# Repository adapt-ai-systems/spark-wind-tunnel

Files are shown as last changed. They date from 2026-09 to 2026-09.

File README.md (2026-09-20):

# spark-tunnel-share — a 3D-printed wind tunnel for two NVIDIA DGX Sparks

A printed ducted box that force-cools **two DGX Spark mini computers
stacked flat**, one above the other, with a single 140 mm fan at the front
and an open rear. Three of these cases were built and put into daily
service; this repo is the version-four design exactly as built — the CAD,
the printable STLs, the settings that worked, and the ones that didn't.

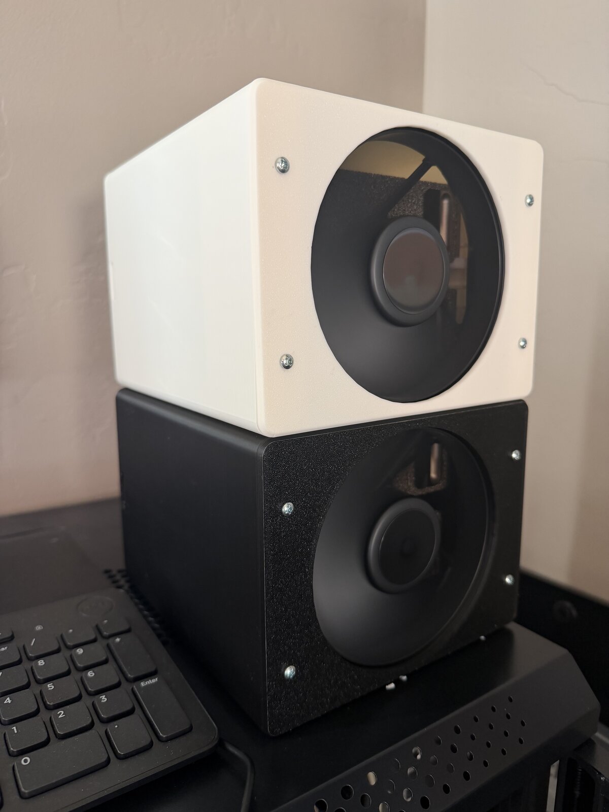
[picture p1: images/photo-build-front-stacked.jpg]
Assembled cases


## What v4 is

Two Sparks lie flat, one above the other, behind a screwed-on fan bezel,
with the rear open. Versus the earlier versions (see
[docs/DESIGN-HISTORY.md](docs/DESIGN-HISTORY.md)):

- **No center tray.** An earlier design supported the upper machine on a
  middle plate; it was 2–3 mm too tight and printed badly. The upper Spark
  now rides on **C-channel side supports** molded into the side walls: a
  reinforced bottom ledge, a top ledge, and flow-parallel ribs between.
- **Positive retention.** The fan bezel is **screwed** on with four #6-32
  screws and the rear locking bar is screwed down with one more — no
  friction fits or snap hooks holding the computers in.
- **Vented rear bar (rev 8).** The solid rear bar blocked the rear exit of
  the 17 mm air gap between the Sparks; it now has seven 20 x 15 mm windows
  while the 3 mm retaining lips stay solid.

Air path: fan → plenum → through both Sparks and around them through an
equal 17 mm gap on every side → open rear. The equal-gap layout and the
opening-area reasoning are in [docs/SPEC.md](docs/SPEC.md); measured cooling
numbers (and their honest limits) are in [docs/THERMAL.md](docs/THERMAL.md).

## Printed parts

| Part | STL | Print time | Material | Notes |
|---|---|---|---|---|
| Body | [stl/body.stl](stl/body.stl) | ~12 h | ~720 g PLA | prints rear face down, warp recipe (see below) |
| Bezel | [stl/bezel.stl](stl/bezel.stl) | 58–69 min | ~50 g PLA | front face down |
| Lock bar | [stl/lockbar.stl](stl/lockbar.stl) | ~30 min | ~20 g PLA | vented rev 8, rear face down |

Print settings and the failure log that produced them — corner warping, the
brim widths that fixed it, bed temperature, and a nozzle-blob/first-layer
story — are in [docs/PRINT-NOTES.md](docs/PRINT-NOTES.md). The short
version: PLA, bed 65 °C, 15 mm inner+outer brim on the body, part fan
15–30 % and off for the first five layers, one part per plate.

## Bill of materials

| Item | Qty | Spec |
|---|---|---|
| NVIDIA DGX Spark | 2 | 45 x 150 x 150 mm body (measured) |
| Arctic P14 Pro fan | 1 | 140 x 140 x 27 mm, 4-pin, 400–2500 rpm |
| #6-32 screws | 5 | 4x bezel into the printed fan rails, 1x lock-bar tab into the wall pad |
| PLA filament | ~800 g | per case |
| Printed parts | 3 | above |

The pedestal height and flare dimensions used in the CAD are from the
community design [jvr0x/dgx-spark-rack](https://github.com/jvr0x/dgx-spark-rack)
(measured from a reference STL) — worth verifying against your own machine
with a rule; the box geometry is parametric if you need to adjust.

## Regenerating the STLs from the CAD

The single parametric source is `cad/spark-box-v4.scad` (OpenSCAD). Each
part module also outputs in its print orientation:

```sh
openscad -o stl/body.stl    -D 'part="body"'    cad/spark-box-v4.scad
openscad -o stl/bezel.stl   -D 'part="bezel"'   cad/spark-box-v4.scad
openscad -o stl/lockbar.stl -D 'part="lockbar"' cad/spark-box-v4.scad
```

`part="assembly"` and `part="cutaway"` (the default is assembly) render the
full box; a set of `chk_*` parts support the fit checks. The file also
echoes the front-face vs bypass-gap area ratio on every load.

## Photos

Assembled black and white cases, front and rear:

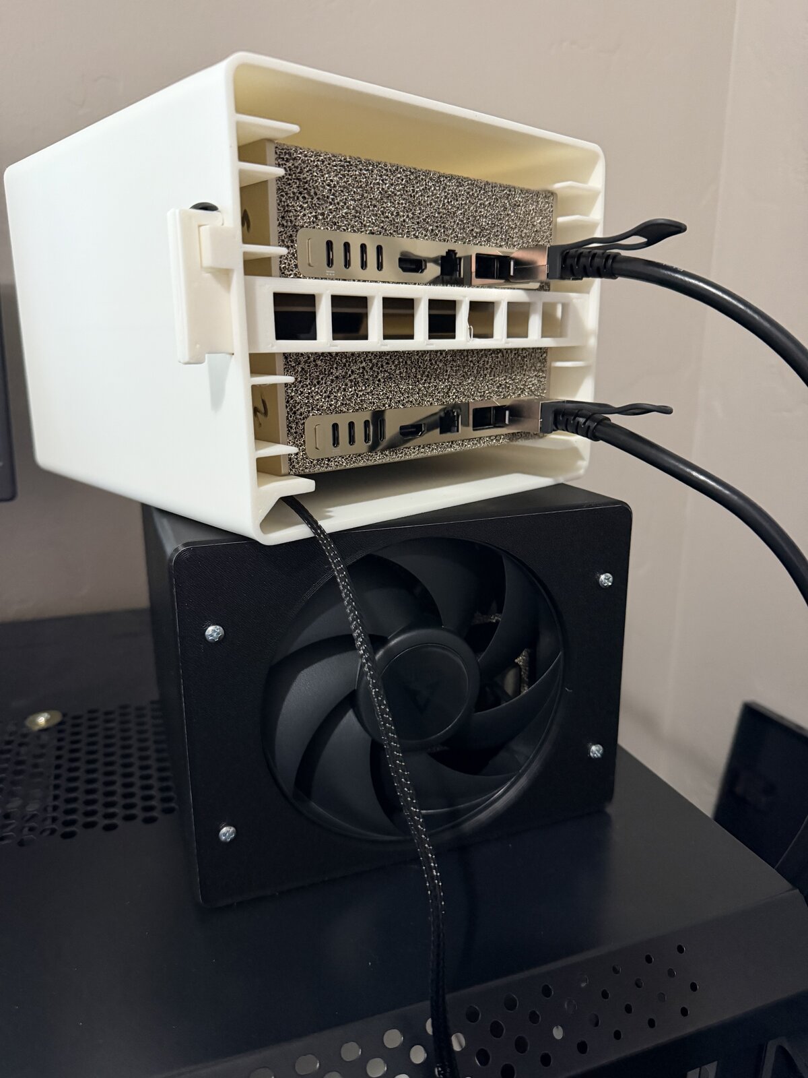
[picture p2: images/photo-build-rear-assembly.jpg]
Rear, white over black

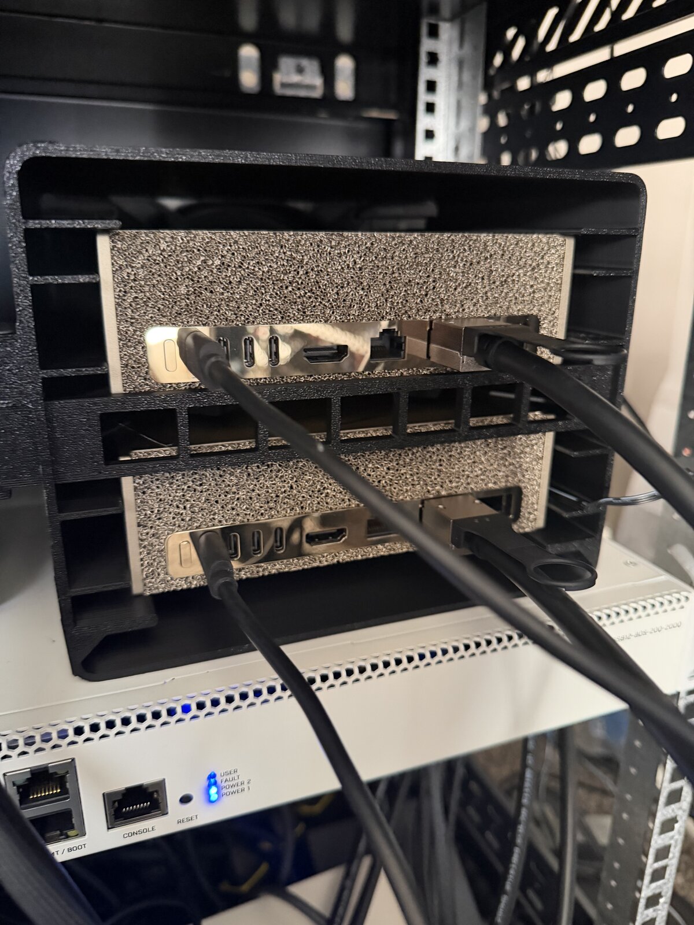
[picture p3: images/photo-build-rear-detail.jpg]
Rear detail, vented lock bar and I/O access


CAD renders (OpenSCAD):

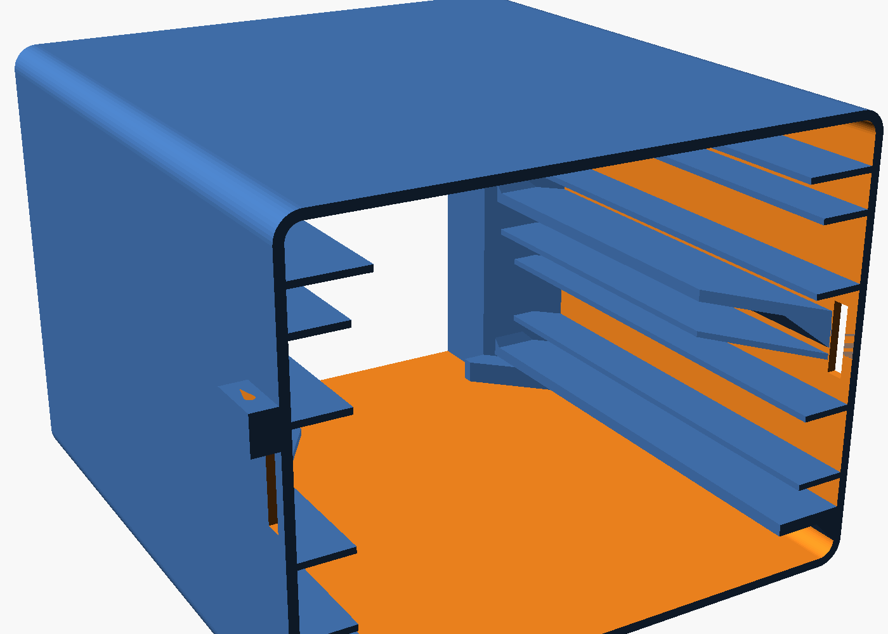
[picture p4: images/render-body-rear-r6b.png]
Body with rear ledges

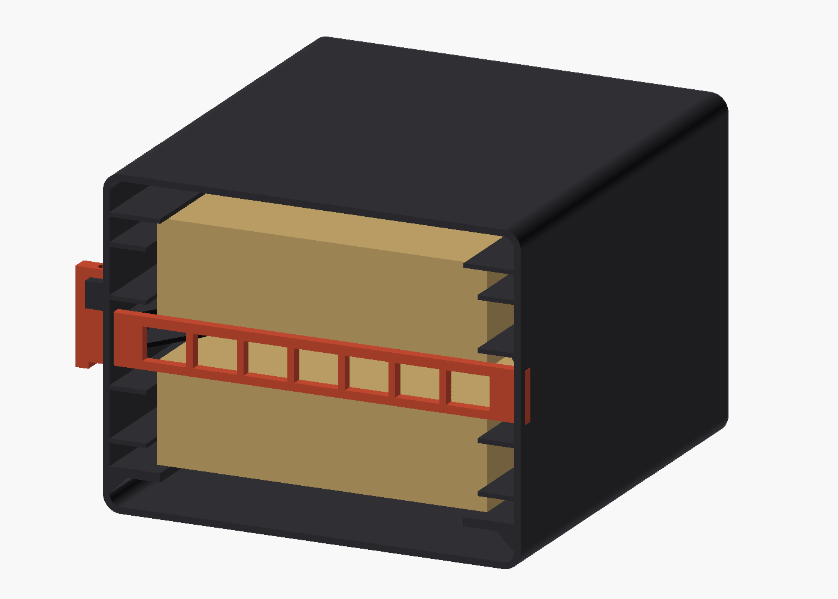
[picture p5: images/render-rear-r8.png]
Rear, rev 8

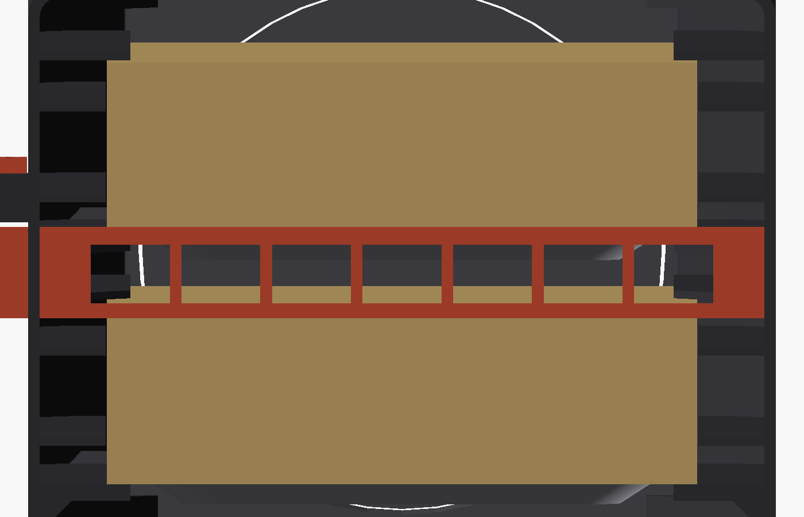
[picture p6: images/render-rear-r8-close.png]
Rear close, rev 8

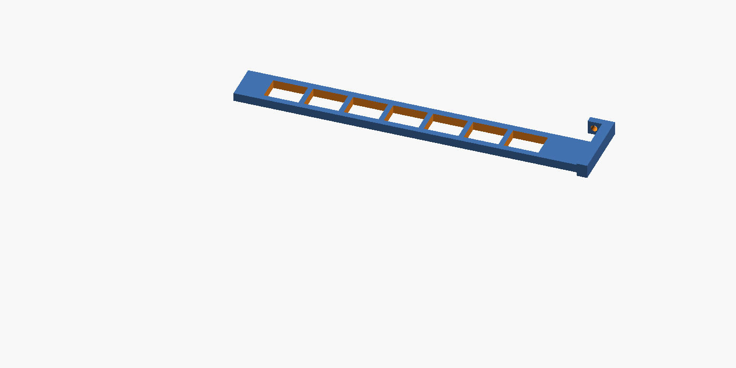
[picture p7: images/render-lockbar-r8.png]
Lock bar rev 8


## Credit

- [jvr0x/dgx-spark-rack](https://github.com/jvr0x/dgx-spark-rack) —
  measured DGX Spark pedestal dimensions used in the CAD.
- The rear locking-bar concept follows the community "whpthomas" rack bar
  idea, adapted to screwed retention and ventilation.

## License

MIT — see [LICENSE](LICENSE). Copyright (c) 2026 spark-tunnel-share
contributors.

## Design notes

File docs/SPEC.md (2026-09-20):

# Original requirements spec (Stage 0)

This is the requirements document written before the first build of this design family; the file it describes became the shipped CAD as `cad/spark-box-v4.scad`.

Owner: the project owner. Lines are the owner's words or numbers unless marked
(design note). "Assumed" means unmeasured and blocks Stage 1.

## Layout (owner, 2026-09-09)

| # | Requirement | Source |
|---|---|---|
| L1 | Two Sparks stacked flat, one above the other | "stacked is fine as long as there is a gap around them" |
| L2 | A gap around the exterior of each Spark; the metal shell dissipates heat and must be cooled | "the exterior of the sparks are metal and are designed to dissipate heat" |
| L3 | Sides solid, no honeycomb | v1 feedback |
| L4 | Front centre strip solid (v1 ribs snapped) | v1 feedback |
| L5 | Sparks held tight, enclosed, not loose | v1 feedback; whpthomas locking bar liked |
| L6 | Power button reachable with the box assembled | v1 feedback; in the stacked layout the rear is open so L6 is met by layout |
| L7 | Fan plug fits its exit; cord exit does not block plugging the Sparks in | v1 feedback |

## Airflow (owner, 2026-09-09)

| # | Requirement | Source |
|---|---|---|
| A1 | Fan: the owner's 140 mm (Arctic P14 Pro) | "the fan is my 140" |
| A2 | Air must exit around the Sparks as well as through them | "We will need air exiting around the sparks" |
| A3 | Opening AREA ratio 70:30, Spark faces to bypass gap (fixed geometry, no shutter) | "Let's just do like 70/30 face to gap ratio" (2026-09-09) |
| A3b | SUPERSEDES A3 (rev 4, later on 2026-09-09): equal gap on every side of the Sparks and between them; with the 141 mm interior that is 17 mm and the area ratio becomes 54:46 | "I want equal space between the sparks as is around them" |
| A4 | The around-path is a thin gap held off the shell by ribs parallel to the airflow | "a thin area around them held out by ribs that are parallel to wind-flow" |
| A5 | Cooling test on v1 decides the bottom-intake positions (v1 plan) | earlier |

## Mating objects

| Object | Dimension | Value | Source | Status |
|---|---|---|---|---|
| Spark | body W x L x H | 45 x 150 x 150 | caliper measurement 2026-09-05 | measured |
| Spark | pedestal height | 6 | jvr0x/dgx-spark-rack README (measured from reference STL; teardowns 51.2 total) | from community STL, verify with a rule |
| Spark | pedestal flare | 111 x 101 at the desk -> 128.6 x 118.6 at the chassis, i.e. ~8.8 mm run per side over the 6 mm height | jvr0x README | from community STL, verify |
| Spark | overall height incl. pedestal | 51.5 | jvr0x README / NVIDIA 50.5 | published |
| Spark | power button | on the BACK, above the USB-C power port | owner, 2026-09-09 | stated |
| Fan plug | standard 4-pin fan plug ("square 4pin"): 2.54 pitch housing ~10.7 x 6.6 mm, ~8 mm tall; cable 400 mm | operator + Arctic spec sheet + Molex KK254 housing dims | housing size from catalog, verify in hand |
| P14 Pro | 140 x 140 x 27 mm, 240 g, 400-2500 rpm, 110 cfm, 5.2 mmH2O, 12 V 0.35 A, cable 400 mm, 4-pin fan plug | Arctic spec sheet PDF | catalog; hole spacing 124.5 assumed (standard 140), verify |

## Open (design note)

- A3 is an AREA ratio by the owner's decision; the resulting flow split is
  unknown until the cooling test (A5). It was flagged that the gap will carry
  more than 30 % of the flow because it has less resistance than the Spark;
  the owner chose the fixed ratio anyway.

## Rev 5 (2026-09-10, owner, after the first full print)

| # | Requirement | Source |
|---|---|---|
| R1 | Screws hold the fan shroud (bezel), not hooks | "screws to hold the fan shroud, not hooks" |
| R2 | The tray (middle layer) must print cleanly, no fused support | "the middle layer print was messed up so we need to do that better next time" |
| R3 | No friction retention; assembled box is one secure unit | "I don't like friction holding something... This needs to act as one secure unit" |
| R4 | Screws: #6-32 (owner wrote "6-29", read as 6-32) | chat |

## Rev 6 (2026-09-10, owner): no tray

| # | Requirement | Source |
|---|---|---|
| R5 | The Sparks are locked in by the ribs on the sides and do not require a support in between them | "the sparks should be locked in by the ribs on the sides and should not require a support in between them" |

## Rev 6b (2026-09-11, owner): reinforce the load-bearing ledge

| # | Requirement | Source |
|---|---|---|
| R6 | Bottom ledges 4 mm thick with an 8 mm 45-degree gusset to the wall | fit feedback on the weight-bearing ledges |

## Rev 8 (2026-09-13): vented lock bar

The solid rear bar blocked the rear exit of the 17 mm gap between the Sparks.
Rev 8 adds a row of seven 20 x 15 mm windows across that band; the 3 mm lips
that retain the Sparks stay solid.

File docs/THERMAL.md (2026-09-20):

# Cooling evidence — one short load test, honestly bounded

## Finding

A September 9 sample run shows a **10.2 °C sample-average GPU-temperature
difference** between the two machine pairs: the pair installed in an
enclosure ran cooler than the pair outside one. This is consistent with the
owner's recollection of roughly 10–15 ° cooler operation.

**Caveat up front:** the test predates the version-four case in this repo,
and the tested case revision is not recorded. Treat this as evidence for the
wind-tunnel project overall, not a validation of the exact design here.

## Method as recorded

- Date: September 9, 15:32 UTC. Four NVIDIA DGX Spark machines had their
  1989 MHz clock lock removed for the test and restored afterwards.
- Load: five minutes of parallel inference requests against one shared
  model endpoint served by the four machines as a tensor-parallel ring —
  not four independent workloads.
- Sampling: the four machines were queried sequentially with
  `nvidia-smi` (GPU temperature, graphics clock, reported GPU power,
  utilization) with a 15 s sleep between rounds; 21 rounds, 84
  observations. The labels 0s–300s are nominal: query overhead adds time,
  readings are not simultaneous. This is an *intended five-minute load
  test*, not a timed steady-state experiment.

## Results

Machines relabeled; the original pairing is preserved.

| Unit | Group | First recorded °C | Last recorded °C | Peak recorded °C | Mean of 21 samples °C |
|---|---|---:|---:|---:|---:|
| Tunnel A | Enclosed | 36 | 53 | 53 | 50.38 |
| Tunnel B | Enclosed | 35 | 51 | 54 | 47.95 |
| Compare A | Open | 43 | 63 | 66 | 57.95 |
| Compare B | Open | 45 | 65 | 69 | 60.86 |

| Statistic | Value | Note |
|---|---:|---|
| Pair means, all 21 rounds | 49.17 °C vs 59.40 °C | difference **10.24 °C**; unweighted sample average, includes warm-up |
| Final five rounds (nominal 240–300 s) | difference **12.80 °C** | descriptive late-window subset, not an independently defined steady state |
| Final recorded round | 53/51 °C vs 63/65 °C | difference **12.0 °C** |
| Per-machine peaks | 53/54 °C vs 66/69 °C | difference of peak means **14.0 °C**; peaks are a different statistic, do not substitute for the average |

## What the raw record does **not** support

- **Not identical operating points.** Across the record, graphics clocks
  span 2405–2528 MHz and reported GPU power spans 12.08–40.72 W; the warmer
  pair generally drew more reported power.
- **No demonstrated steady state** for every machine; one unit was still
  climbing at the end.
- **No throttle-reason data** in the samples — absence of recorded
  throttling was not verifiable per machine throughout.
- **Throughput figures** quoted in a contemporary chat summary were derived
  by dividing generated output by a hard-coded 300 s window; no
  case-on/case-off speed experiment was performed. Do not use them as
  cooling evidence.

## Limits on causal claims

- This is a **cross-machine comparison, not a controlled before/after
  crossover**. The first recorded pair-mean gap is already 8.5 °C; the first
  sample is not a documented equivalent bare-machine baseline, and the
  enclosed pair may already have benefited from the case at sample one.
- Room temperature, intake-air temperature, placement, fan RPM/duty, exact
  fan model in the tested case, enclosure revision, and repeat trials are
  not documented. Power readings are GPU telemetry, not wall power. One
  short run gives no error bars and no statistical significance.
- The current design's rear ventilation and retention changes happened
  after this test.

## Qualitative update (September 17)

The owner reports the version-four cases run the Sparks at full load without
underclocking, after choosing a higher-speed fan running at roughly half
throttle from two options; noise and airflow comparisons were qualitative.
Reported throughput is unchanged with lower temperatures near 1900 MHz,
without matching clock/workload records. These are user observations, not
measurements included here.

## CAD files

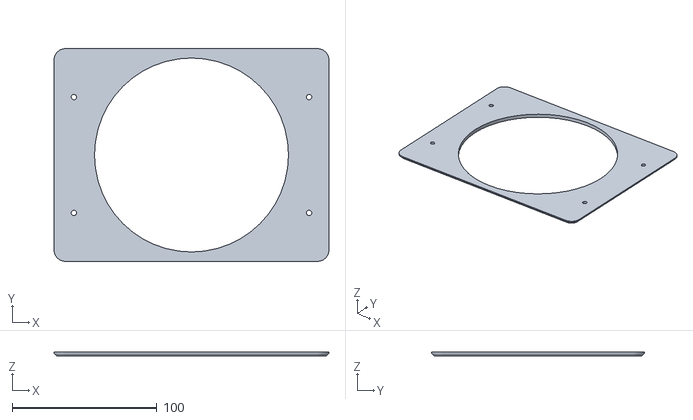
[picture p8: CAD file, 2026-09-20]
stl/bezel.stl
190.0 x 147.0 x 3.00

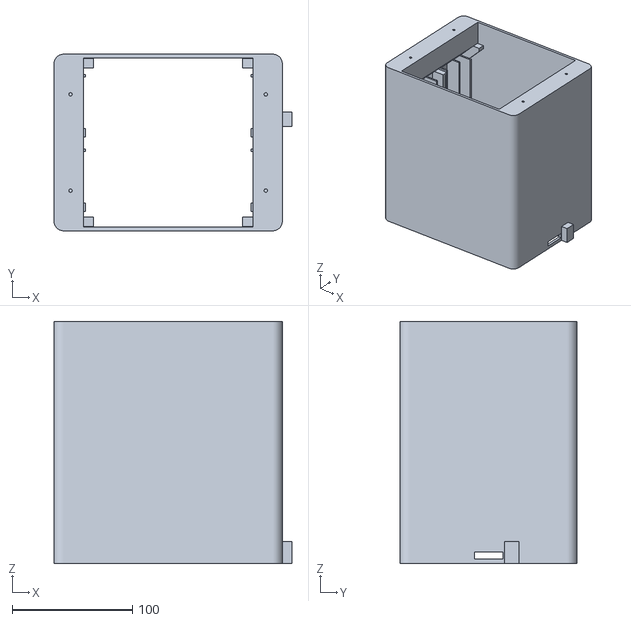
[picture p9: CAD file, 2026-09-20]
stl/body.stl
198.0 x 147.0 x 201.5

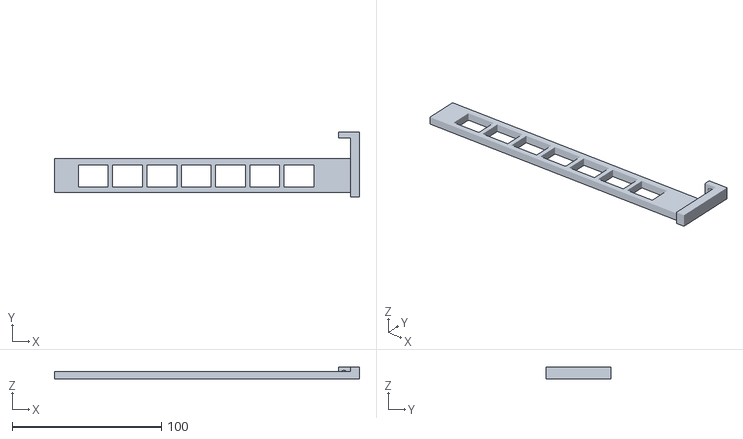
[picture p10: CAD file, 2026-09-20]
stl/lockbar.stl
204.5 x 43.8 x 8.00

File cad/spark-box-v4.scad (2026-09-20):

// Spark box v2 — two DGX Sparks stacked flat inside a ducted box, 140 mm fan at the front, open rear.
// rev 8 (2026-09-13): lock bar vented. The solid bar blocked the rear exit of the 17 mm gap between the Sparks; it now has a row of windows across that band, the 3 mm lips that retain the Sparks stay solid.
// rev 6 (2026-09-10): NO tray. Each Spark is locked in by C-channel ribs on the side walls: a bottom ledge it sits on, a top ledge over it, the lateral side ribs between. Nothing between the Sparks but air.
// rev 5 (2026-09-10, after the first full print): bezel screwed on (4 x #6-32 into the fan rails, hooks gone); lock bar screwed down (#6-32 through a handle tab into a pad on the right wall); tray underside is a flat slab (no support).
// Spec: ../docs/SPEC.md (2026-09-09). Parts: body, bezel, lockbar (rev 6: no tray). Render views at the bottom.
// Every number here is either from SPEC.md or a design choice marked (design note).
$fn = 48; eps = 0.01;

// ---- mating objects (SPEC "Mating objects") ----
sw = 150;  sl = 150;  st = 45;          // Spark body: width, depth (face->rear), thickness (measured 2026-09-05)
ped_h = 6;                              // pedestal height (jvr0x, verify)
ped_top = [128.6, 118.6];  ped_bot = [111, 101];   // pedestal flare, chassis -> desk (jvr0x, verify)
fan = 140; fan_t = 27; fan_hole = 124.5; fan_bore = 134; fan_screw = 5.2;   // P14 Pro spec sheet; hole spacing = standard 140 (verify)

// ---- design choices (design note) ----
wall  = 3;      // all walls
plen_ih = fan + 1;   // interior height 141: fan pocket + clearance (rev 4: one height end to end - simple and smooth)
IH = plen_ih;
g     = (IH - 2*st)/3;   // 17: EQUAL gap everywhere — floor, between the Sparks, ceiling, and both sides (rev 4)
rib_w = 2;      // flow-parallel ribs holding each Spark off the walls (ledge and side rib thickness)
ledge_reach = g + 6;   // (rev 6) 23: side ledges run from the wall to 6 mm under each Spark edge, 4.7 mm outside the 128.6 pedestal flare (same reach as the old rib_x)
ch_cl = 1.0;    // (rev 6) channel height = st + ch_cl: top ledge sits 1.0 above the Spark (printed rib heights stack up)
seat_t = 4;     // (rev 6b: reinforce the ledge carrying the weight) bottom ledge thickness
gus = 8;        // (rev 6b) 45 deg gusset under each bottom ledge: gus down the wall, gus out along the ledge
bezel_t = 3;    // front bezel plate
fan_cl = 0.5;   // fan pocket clearance
stop_d = 4;     // fan rear stop blocks
mix_d = 10;     // fan exhaust -> chamfer start
plen_d = bezel_t + fan_t + fan_cl + stop_d + mix_d;   // plenum depth (44.5)
r_out = 8; r_in = 5;   // outer / inner corner radii (smooth exterior)
hook_w = 10; hook_t = 1.5; hook_l = 9; barb = 1.0;   // bezel snap hooks (4)
rear_d = 10;    // room behind the Sparks for the lock bar and cables
scr_pilot = 2.9; scr_clr = 3.7; scr_x = 13.75;   // (rev 5) #6-32 screws: pilot in plastic, clearance in the part; bezel screws sit in the fan-rail centres x = 13.75 / OW-13.75
bar_t = 5; bar_lip = 3;   // lock bar: thickness, VERTICAL overlap onto each Spark's rear edge (rev 4c: bar_h derived so BOTH Sparks get the full lip; it was 20 = only 0.3 on Spark 2)
vent_w = 20; vent_strut = 3; vent_m = 1.0;   // (rev 8) lock bar vent windows: width, strut between windows, solid margin kept above/below the window inside the inter-Spark gap (windows are vent_h = g - 2*vent_m = 15 tall; lips stay solid)
bar_gap = 0.5;  // slot starts this far behind the Spark rears (bar face 0.8 behind them: fore-aft play, spec L5 "held tight")
stop_h = 3;     // front stop tabs on the rib ends

// ---- derived ----
IW = sw + 2*g;                 // interior width 184
OW = IW + 2*wall;              // 190
OH = IH + 2*wall;              // body outer height 147, front to rear
PH = OH;                       // (plenum outer height = body height)
ch = 0;                        // no chamfer any more
z_floor = wall;
stack_h = st + g + st;   // (rev 6) Spark 1 + air gap + Spark 2 = 107
z_s1 = wall + (IH - stack_h)/2;  // Spark 1 body bottom = wall + g (20); pedestal hangs in the floor gap
gb = z_s1 - z_floor;           // floor gap = g (floor ribs this tall)
z_s2 = z_s1 + st + g;          // Spark 2 body bottom (rev 6: one clear gap g between the Sparks, no tray)
bar_h = (z_s2 - (z_s1 + st)) + 2*bar_lip;   // 23: spans the inter-Spark gap plus bar_lip onto each rear edge
z_ceil = OH - wall;            // ceiling underside
gt = z_ceil - (z_s2 + st);     // ceiling gap = g
y_face = plen_d;               // Spark faces at the end of the plenum
y_rear_s = y_face + sl;        // Spark rears
L = y_rear_s + rear_d;         // body length 204.5
bar_y = y_rear_s + bar_gap + 0.3; bar_z0 = z_s1 + st - bar_lip + 0.3;   // lock bar front face / bottom
pad_z0 = bar_z0 + bar_h + 1.5; pad_h = 12;   // (rev 5) screw pad above the slot
cx = OW/2; cz = OH/2;          // fan axis
side_rib_dz = [10, st - 10 - rib_w];   // side-wall ribs per Spark (above its body bottom)

// ---- opening-area check (SPEC A3: 70:30 by area) ----
a_face = 2 * sw * st;
a_floor = IW*gb - 2*(seat_t*ledge_reach + gus*gus/2);   // (rev 6b) two reinforced bottom ledges + gussets of Spark 1 lie in the floor gap
a_mid = IW*g - 2*rib_w*ledge_reach - 2*(seat_t*ledge_reach + gus*gus/2);   // (rev 6b) Spark 1 top ledges + Spark 2 reinforced bottom ledges
a_top = IW*gt - 2*rib_w*ledge_reach;
a_side = 4 * g * st - 8*rib_w*(g - 0.3);              // 8 lateral side ribs
a_gap = a_floor + a_mid + a_top + a_side;
echo(str("face area ", a_face, "  gap area ", a_gap, "  face:gap = ", round(100*a_face/(a_face+a_gap)), ":", round(100*a_gap/(a_face+a_gap))));

module wedge(x0, y0, w, d) { polygon([[x0, y0], [x0 + w, y0], [x0 + w, y0 + d], [x0, y0 + d + w]]); }   // XY profile: full width for d, then a 45 deg taper back to the wall
rib_len = L - y_face;   // (rev 4b) ribs run to the rear face so they start on the bed when the body prints rear-down
module ledge_xy(full) {   // (rev 6) side ledge plan (XY), from y_face. full: to the rear face. Otherwise (the two ledges inside the lock bar's z band) it ends at the Spark rear with a taper back into the wall, so it clears the bar slot and still prints rear-face-down without support
  if (full) translate([0, y_face]) square([ledge_reach, rib_len]);
  else polygon([[0, y_face], [ledge_reach, y_face], [ledge_reach, y_rear_s - 1.5*ledge_reach], [0, y_rear_s]]);   // taper rises 1.5x its run (56 deg): a 45 deg one failed the bridge gate on its first layer
}
module ledge(full, t = rib_w) { linear_extrude(t) ledge_xy(full); }
module seat(full) {   // (rev 6b) weight-bearing bottom ledge: seat_t thick with a 45 deg gusset underneath (XZ triangle, cut to the ledge's plan so its rear end follows the same taper). Origin = ledge top's underside corner at the wall, z up = ledge
  translate([0, 0, -seat_t]) ledge(full, seat_t);
  intersection() {
    translate([0, 0, -seat_t - gus]) linear_extrude(seat_t + gus) ledge_xy(full);
    rotate([90, 0, 0]) translate([0, 0, -L]) linear_extrude(L) polygon([[0, -seat_t - gus], [gus, -seat_t], [0, -seat_t]]);
  }
}
module tab(h, w = rib_w) { translate([0, y_face - 3, 0]) hull() { cube([w, 3, h]); cube([w, eps, h + stop_h]); } }   // front stop tab (rev 4e): the stop face is a 45 deg ramp rising from the rib top at y_face to h+stop_h at y_face-3, so rear-face-down it is self-supporting (the old square 2 x 3 mm tab made the slicer stand a 160 mm support sheet under it)
module rail_wedge(extra = 0) { wedge(wall - extra, bezel_t, cx - fan/2 - fan_cl - wall + extra, fan_t + fan_cl); }
module rrect(w, h, r) { offset(r) offset(-r) square([w, h], center = true); }

module spark(i) {   // lying flat, pedestal down, face at y_face
  z = (i == 0) ? z_s1 : z_s2;
  translate([wall + g, y_face, z]) {
    color([0.78, 0.66, 0.42]) cube([sw, sl, st]);
    color([0.55, 0.55, 0.58]) translate([sw/2, sl/2, 0]) mirror([0, 0, 1])
      hull() { linear_extrude(eps) rrect(ped_top[0], ped_top[1], 8); translate([0, 0, ped_h - eps]) linear_extrude(eps) rrect(ped_bot[0], ped_bot[1], 8); }
  }
}
module fan_model() {   // sits in the pocket behind the bezel; hub + blade disc are for the renders only
  color([0.3, 0.3, 0.32]) translate([cx - fan/2, bezel_t + fan_cl/2, cz - fan/2]) {
    difference() { cube([fan, fan_t, fan]); translate([fan/2, -1, fan/2]) rotate([-90, 0, 0]) cylinder(d = fan_bore, h = fan_t + 2); }
    translate([fan/2, 0, fan/2]) rotate([-90, 0, 0]) { cylinder(d = 45, h = fan_t); translate([0, 0, fan_t/2 - 1]) cylinder(d = fan_bore - 2, h = 2); }
  }
}
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

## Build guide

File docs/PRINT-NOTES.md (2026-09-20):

# Print notes — what failed, what finally worked

Distilled from the full print/fit log of this project. Machine identifiers,
material lot labels, and printer-queue details are stripped; the failures and
the settings that fixed them are kept verbatim in substance.

All parts are PLA, printed on a Creality K2 (enclosed, 260 mm square plate).
Orientation per part: body and lock bar print with their rear face on the
bed; the bezel prints front face down.

## The problems we hit

### 1. Corner lifting on tall, flat-footed parts (the big one)
- First full body print was cancelled after ~25 min: one thin isolated inner
  rib fin near a corner had a strand curling off its tip. That fin had an
  outside-only brim and no foot of its own.
  **Lesson: every thin isolated piece needs a brim that anchors it on both
  sides (outer AND inner), not just around the outside.**
- A flat slab part (the later-abandoned tray) printed directly on the plate
  lifted its front corners at ~33%. The fix that held:

  | Setting | Value |
  |---|---|
  | Brim width | 15 mm, outer and inner |
  | Bed temperature | 65 C |
  | Part cooling fan | max 30 %, min 15 % |
  | Part fan first 5 layers | off |
  | Auxiliary fan | 0 |

  We call this the **warp recipe** below. A re-slice of the same geometry with
  this recipe completed with dead-flat corners.
- The first body re-slice (rev 6, no-tray design) still used the old cooling
  defaults (bed 60, fan 50/30, brim 8) and lifted its two rear corners about
  30 minutes in — the rear face is the whole 198 x 147 mm print footprint, so
  it is the worst place for a corner to lift. Re-sliced with the warp recipe
  plus the inner+outer brim, the body then printed ~12 h twice in black and
  once in white with no pause and no error.

### 2. Small screw-tab features popping off mid-print
- Printing the bezel and lock bar on one plate failed at ~21 min: a
  screw-hole ring came off the plate. The tab is a 4 mm strip with a hole and
  a tiny cross-section foot.
  **Lesson: print these parts individually, and give small screw lugs an
  inner+outer brim.** Printed alone with the right brim, both finished clean.

### 3. First-layer adhesion on white in a cold room
- A white bezel attempt never stuck on the first layer (classic spaghetti).
  A second attempt laid the first brim line as a loose rope instead of
  squished flat, even at 65 C bed.
- Root cause found by inspection: a **blob on the nozzle tip** fouled the
  strain-gauge Z probe, so the probe reported a plate position that was too
  low and the first layer printed too high. Fix: heat the nozzle to ~200 C,
  wipe the blob off, wash the plate (soap and water or IPA), close the door
  to kill drafts. Third attempt: brim pressed flat and wide, part completed.
- Note: the same bezel gcode succeeded in black with conservative settings
  and failed in white in a colder garage. When in doubt, use the warp recipe
  — it worked for both colors.

### 4. Horizontal screw pilots bridged badly
- The lock-bar screw pilot drilled horizontally into its pad (a 2.9 mm hole
  lying flat when the body prints rear-down) failed the slicer's bridge check
  at its crown. **Fix: teardrop the pilot** — pointed apex toward the front
  (which is "up" in the print orientation), pad extended to keep the apex
  inside the part. The slicer then showed only a 0.13 mm residual on the apex
  tip layer, which the screw taps through anyway.
- A ledge taper was also steepened from 45 to 56 degrees to pass the same
  gate; it was not the actual cause but was kept.

## The recipe that finally worked

| Part | Orientation | Recipe | Result |
|---|---|---|---|
| body (rev 6b, r7c) | rear face down | warp recipe + inner/outer brim 15 mm | ~11.9 h, ~720 g PLA, three clean prints |
| bezel (r6/r7w) | front face down | warp recipe (mandatory for white / cold garage) | 58–69 min, ~50 g |
| lock bar (r8 vented) | rear face down | inner/outer brim 8 mm, normal fan | ~30 min, ~20 g |

- One part per plate.
- Check the first layer around the 5–10 minute mark. Clean plate, drafts off.
- If the first layer looks like rope instead of flat ribbons, look at the
  nozzle before blaming the plate.

## Fit feedback the geometry absorbed

- Earlier tray-era builds: the tray stack was 2–3 mm too thick and one Spark's
  bottom cover had to be removed to fit the second machine. The no-tray rev 6
  design removes this entirely. The 45 mm Spark thickness used in the CAD was
  confirmed with calipers with the bottom cover installed.
- Completed rev 6b set (Sep 12): "turned out perfect". White set with the
  vented rev 8 bar completed Sep 13; second black set Sep 15.
- Manual pilot-drilling option for the four bezel screws, if you skip the
  printed pilots: on the front rim of the body, at x = 13.75 and 176.25 mm
  from the left outer face, z = 33.5 and 113.5 mm from the bottom outer face;
  2.9 mm (7/64 in) bit, 12 mm deep, straight in. Or use the printed bezel
  itself as the drill template.

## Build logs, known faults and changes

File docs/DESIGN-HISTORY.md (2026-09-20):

# Design history — four physical versions

The sequence below is reconstructed from dated CAD and print/fit records,
anchored by the project owner's descriptions of versions one and four. The
physical sequence is well supported; these numbers are editorial labels, not
literal archive revision names.

## Version one: multi-piece upright chimney enclosure (Sep 4–6)

Two Sparks stand on edge in modular cells connected to a rear chimney with a
top exhaust fan. Separate lids, caps, ties, hood, and cable plates make a
multi-piece assembly. It was glued up and the pieces and gaps proved
unwieldy. A specification dated September 4 describes the cells/chimney
layout; print records show all parts for the two-Spark build complete on
September 6 with the assembly glued that evening. A follow-up brief called
that two-cell build "too big". The older front-push rack proposals are
precursor designs, not additional confirmed physical builds.

## Version two: compact upright box with a bottom plate (Sep 6–9)

The pair remains upright, but a single main shell and removable bottom plate
replace the many-part rack. The fan sits inside under the roof. Honeycomb
openings appear in the roof and sides. Design records date the cup part
complete September 8 (plate same evening), with fit feedback the same day —
openings 6 mm too short, inaccessible controls/cable issues, loose fit — and
the move to a stacked arrangement recorded on September 9. This establishes a
distinct printed design between the first modular enclosure and the stacked
case.

## Version three: first stacked front-fan case, with a tray (Sep 9–11)

Two Sparks lie flat, one above the other, behind a front fan, with an open
rear. A middle tray supports the upper device. Early retention uses bezel
hooks and a friction-fit rear bar, followed by screw-retention revisions and
attempts to fix the tray. The first four-part print set and September 10 fit
feedback are on record; a September 11 fit report says the tray stack was
2–3 mm too thick and one Spark's bottom cover had to be removed to fit the
second machine — that workaround belongs to this build, not to the final
design.

## Version four: no tray, reinforced side supports, positive retention (Sep 10–15) — this repo

C-channel side supports replace the center tray. Weight-bearing ledges gain
reinforcement (rev 6b). Screws secure the bezel and retaining bar (rev 5).
The later rear-bar revision (rev 8) adds seven 20 x 15 mm windows while
retaining the lips that hold the computers in place.

Dated milestones: tray removal decided September 10; reinforced rev 6b
geometry September 11; first completed black set September 12 ("turned out
perfect"); white set with the vented rev 8 bar complete September 13; a
second black set complete September 15. Three version-four cases were built,
each holding two Sparks. The vented bar is a refinement within this final
design family, not a fifth version.

## Remaining limits

The September 9 cooling test (see [THERMAL.md](THERMAL.md)) predates the
first stacked build, and the test records do not identify which of the two
earlier enclosures was installed. Photo-to-build mapping for the earlier
photos is inferred from visible geometry, not filenames.
